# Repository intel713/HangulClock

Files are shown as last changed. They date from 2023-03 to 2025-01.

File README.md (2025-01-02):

# HangulClock
현재 시각에 맞는 한글에 불을 밝힘으로써 시각을 나타내는 시계<br>

# 사용 부품
1 * `Arduino Nano`<br>
36 * `Adafruit Neopixel`(IP30, 60Led/m)<br>
1 * RTC모듈(`DS1302` OR `DS3231`(추천))<br>

# 참고사항
업로드를 하려면 아두이노 IDE 라이브러리에 `Adafruit_NeoPixel`, `ThreeWire` , `RtcDS1302`(`DS1302`의 경우) / `DS3231`(`DS3231`의 경우)라이브러리가 포함되어 있어야 함.<br>
`DS3231` 라이브러리 [GitHub 링크](https://github.com/NorthernWidget/DS3231)<br>
ShortCable:네오픽셀 간 케이블 연결 길이를 최소화 하기 위해 네오픽셀을 지그재그로 배치한 버전(파일 내 LED 인덱스 배치 주석 참고).<br>

__알 수 없는 이유로 DS3231 라이브러리가 제대로 안되는 문제가 발생하여 Adafruit의 RTClib로 대체함.__

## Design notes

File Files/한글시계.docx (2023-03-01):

오 전 후 한 두 세

네 다 섯 여 섯 일

곱 여 덟 아 홉 열

한 두 시 이 삼 사

오 십 일 이 삼 사

오 육 칠 팔 구 분

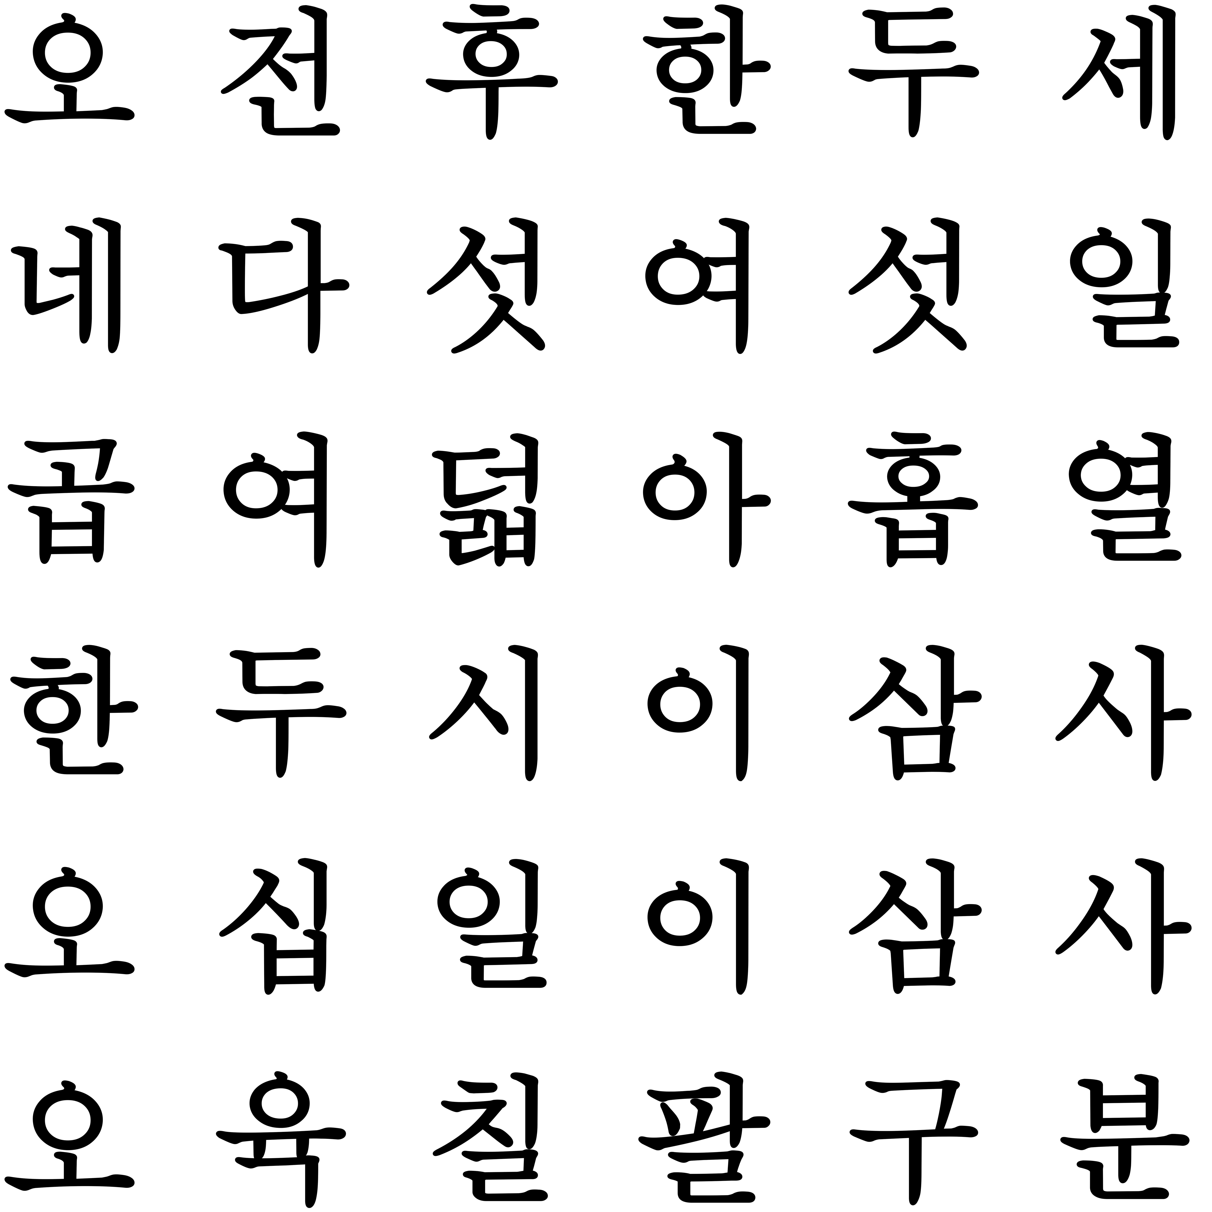
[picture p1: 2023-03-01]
Files/한글시계.png

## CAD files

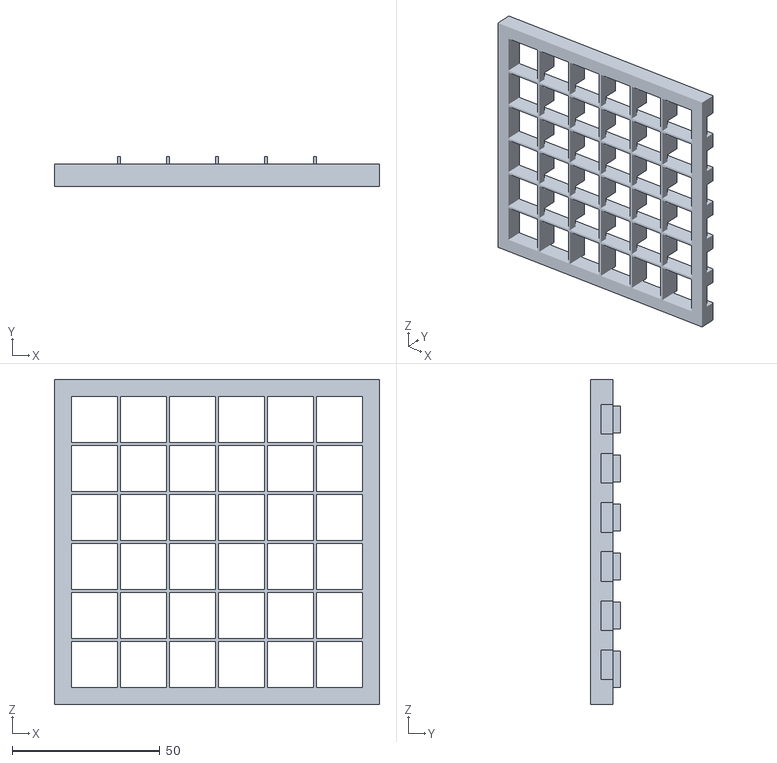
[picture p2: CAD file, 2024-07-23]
STL_V2/sep.stl
110.0 x 10.0 x 110.0

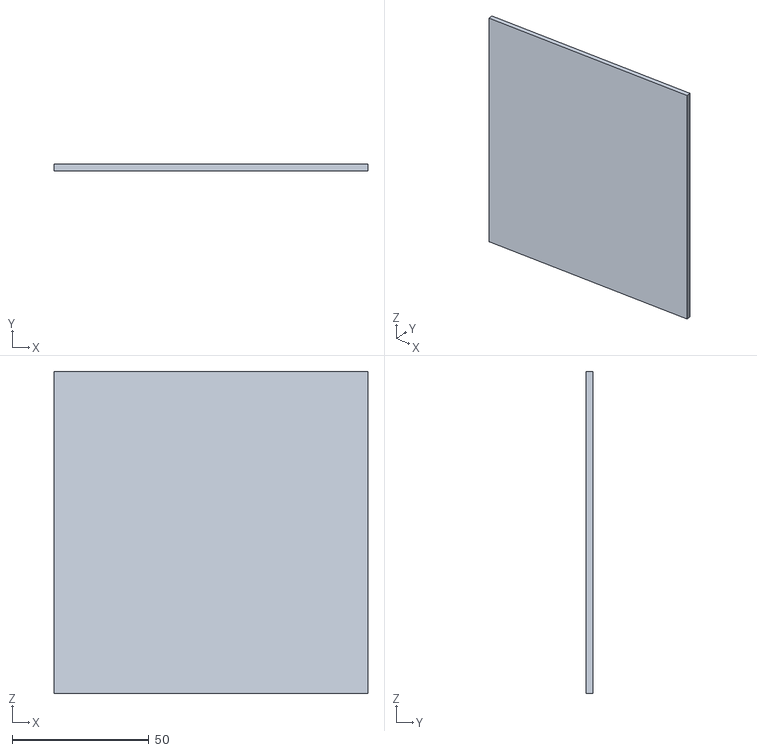
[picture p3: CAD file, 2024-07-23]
STL_V2/back.stl
115.0 x 2.40 x 118.0

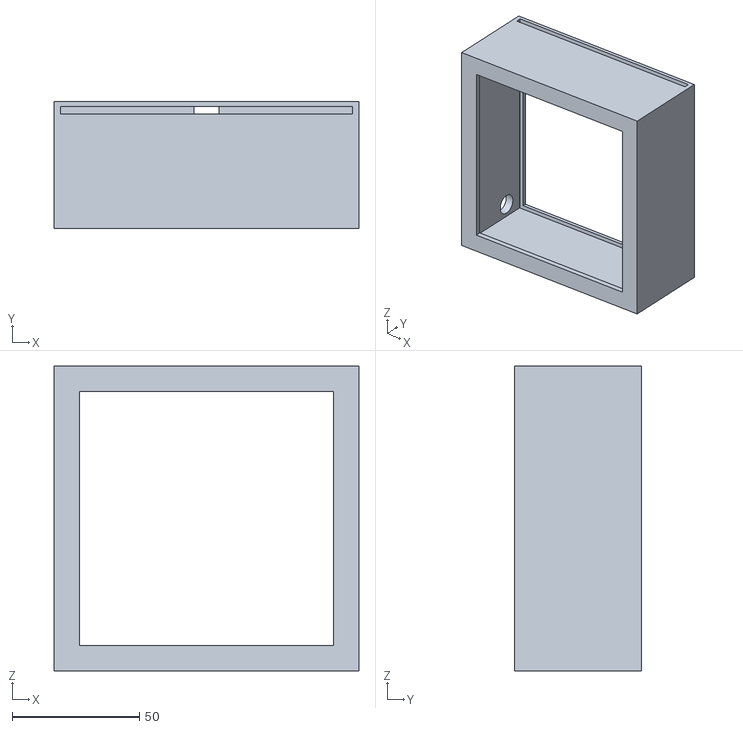
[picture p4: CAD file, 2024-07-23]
STL_V2/case_round.stl
120.0 x 50.0 x 120.0

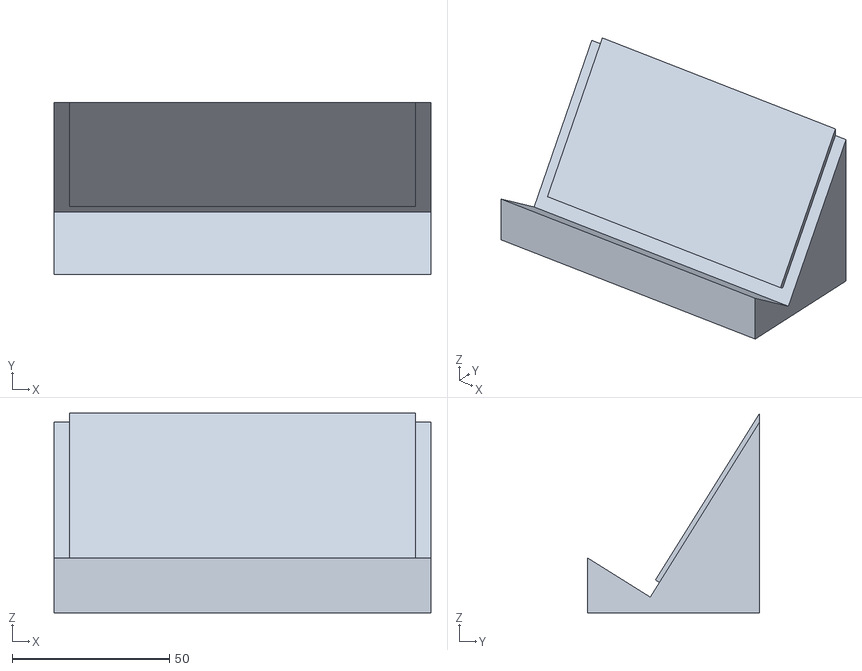
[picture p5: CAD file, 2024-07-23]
STL_V2/support.stl
120.0 x 54.8 x 63.5

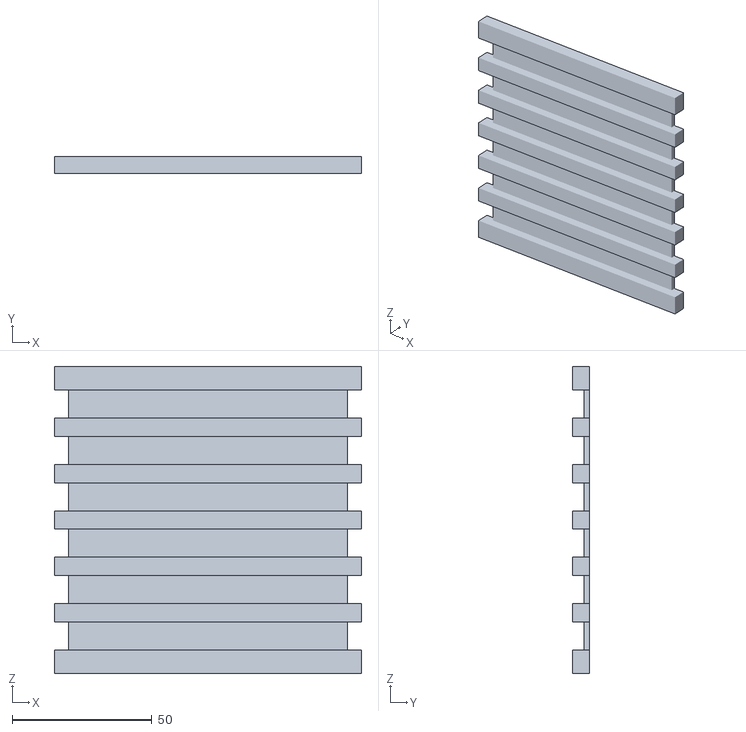
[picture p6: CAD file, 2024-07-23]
STL_V2/led.stl
110.0 x 6.00 x 110.0

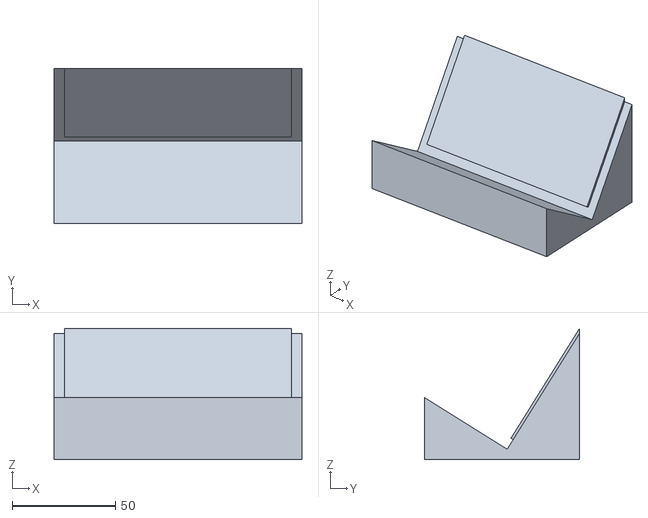
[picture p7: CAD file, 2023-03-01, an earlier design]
STL/Stand.stl
120.0 x 75.0 x 63.4

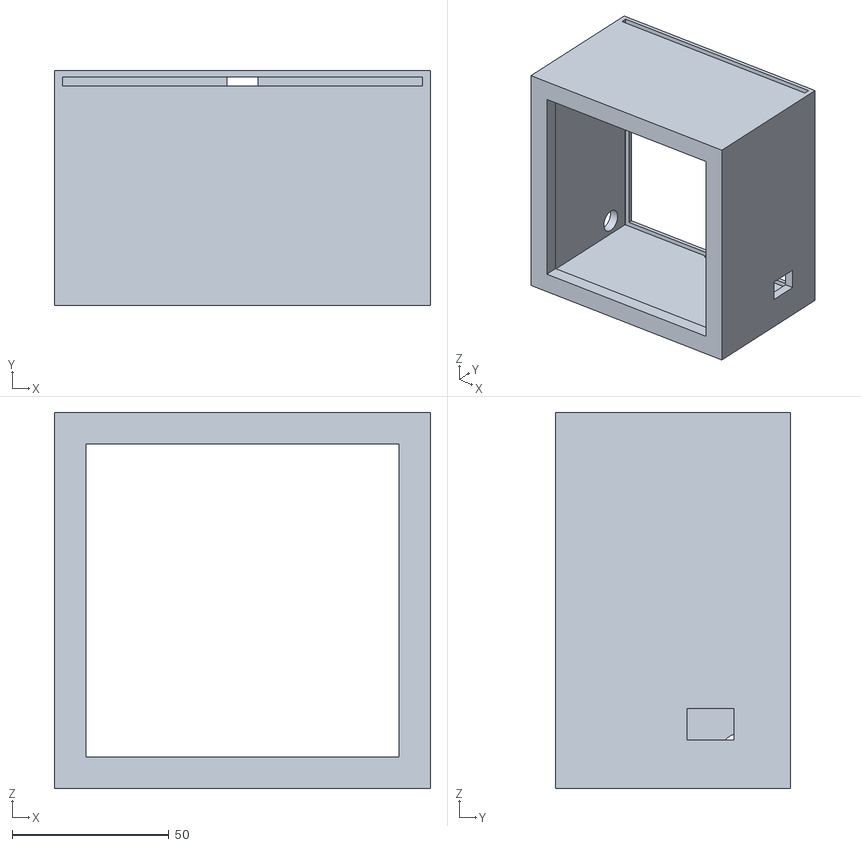
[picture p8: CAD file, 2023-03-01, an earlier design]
STL/Case.stl
120.0 x 75.0 x 120.0

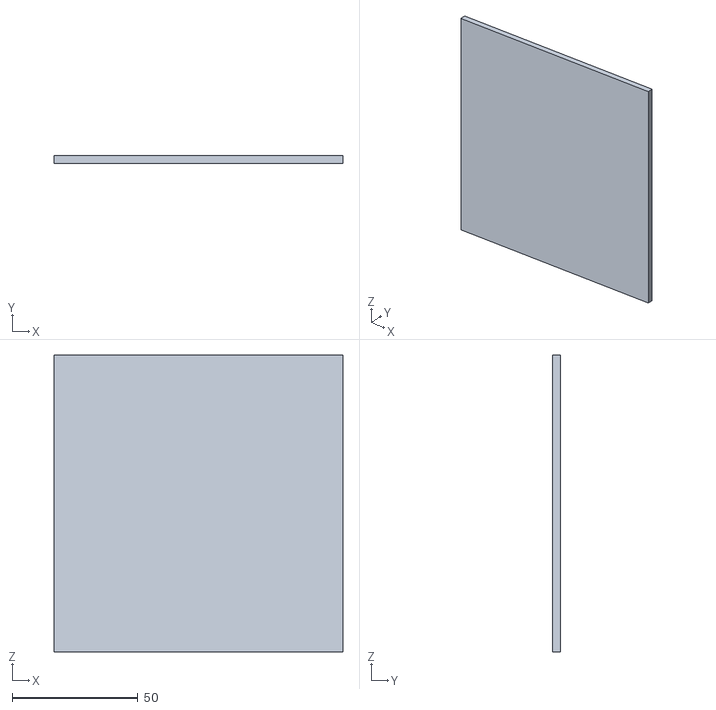
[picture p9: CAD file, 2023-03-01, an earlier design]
STL/Back_Lid.stl
115.0 x 3.00 x 118.0

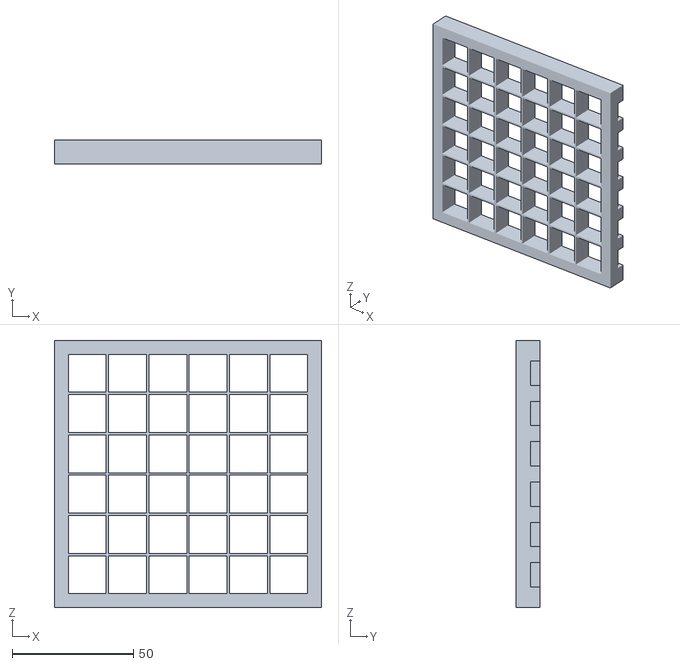
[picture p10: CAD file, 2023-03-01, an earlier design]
STL/Grid.stl
110.0 x 10.0 x 110.0

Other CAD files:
STL_V2/case_usb.stl
STL/Led_Panel.stl

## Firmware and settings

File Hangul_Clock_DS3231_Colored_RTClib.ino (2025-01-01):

//#include <DS3231.h>
#include <Adafruit_NeoPixel.h>
#include <Wire.h>
#include <time.h>
#include "RTClib.h"

#define LED_PIN 3 //네오픽셀 Data 단자와 연결할 핀
#define LED_COUNT 36 //네오픽셀 LED 개수 (6 X 6)

RTC_DS3231 RTC;
Adafruit_NeoPixel strip(LED_COUNT, LED_PIN, NEO_GRB + NEO_KHZ800);

//색과 밝기 설정
#define DEFAULT_COLOR strip.Color(255, 255, 255)
#define BRIGHTNESS 255

#define AM_COLOR strip.Color(255, 255, 32)
#define PM_COLOR strip.Color(96, 64, 255)

#define hour_startH 7000
#define hour_endH 30000

#define minute_startH 500
#define minute_endH 6000

uint32_t hour_color = strip.Color(255, 255, 255);
uint32_t minute_color = strip.Color(225, 115, 44);

/* 위치 구성
오 전 후 한 두 세
네 다 섯 여 섯 일
곱 여 덟 아 홉 열
한 두 시 이 삼 사
오 십 일 이 삼 사
오 육 칠 팔 구 분
00 01 02 03 04 05
06 07 08 09 10 11
12 13 14 15 16 17
18 19 20 21 22 23
24 25 26 27 28 29
30 31 32 33 34 35
*/


bool h12 = false, hPM = false;

bool am = true;
int h = 0;
int m = 0;
//int s = 0;

void setup() {
  strip.begin();
  strip.setBrightness(BRIGHTNESS);
  RTC.begin();
  Serial.begin(115200);
}

void loop() {
  strip.clear();
  setTime();
  setColor();
  setAmPm();
  setHour();
  setMinute();
  strip.show();
  delay(100);

  /*
  for (int i = 0; i <= 23; i++) {
    for (int j = 0; j <= 59; j++) {
      h = i;
      m = j;

      strip.clear();
      setAmPm();
      setColor();
      setHour();
      setMinute();
      strip.show();
      delay(5);
    }
  }
  */
}


void setTime()
{
  DateTime now = RTC.now();
  
  h = now.hour();
  m = now.minute();
  //s = RTC.getSecond();
}

void setAmPm()
{
  if (0 <= h and h < 12){
    strip.setPixelColor(0, AM_COLOR);
    strip.setPixelColor(1, AM_COLOR);
    if (h == 0) {
      h = 12;
      am = true;
    }
  }
  else {
    strip.setPixelColor(0, PM_COLOR);
    strip.setPixelColor(2, PM_COLOR);
    am = false;
    if (h != 12) {
      h = h - 12;
    }
  }
}

void setHour()
{
  strip.setPixelColor(20, hour_color); //시

  if (h == 1) {
    strip.setPixelColor(3, hour_color);
  }
  else if (h == 2) {
    strip.setPixelColor(4, hour_color);
  }
  else if (h == 3) {
    strip.setPixelColor(5, hour_color);
  }
  else if (h == 4) {
    strip.setPixelColor(6, hour_color);
  }
  else if (h == 5) {
    strip.setPixelColor(7, hour_color);
    strip.setPixelColor(8, hour_color);
  }
  else if (h == 6) {
    strip.setPixelColor(9, hour_color);
    strip.setPixelColor(10, hour_color);
  }
  else if (h == 7) {
    strip.setPixelColor(11, hour_color);
    strip.setPixelColor(12, hour_color);
  }
  else if (h == 8) {
    strip.setPixelColor(13, hour_color);
    strip.setPixelColor(14, hour_color);
  }
  else if (h == 9) {
    strip.setPixelColor(15, hour_color);
    strip.setPixelColor(16, hour_color);
  }
  else if (h == 10) {
    strip.setPixelColor(17, hour_color);
  }
  else if (h == 11) {
    strip.setPixelColor(17, hour_color);
    strip.setPixelColor(18, hour_color);
  }
  else if (h == 12) {
    strip.setPixelColor(17, hour_color);
    strip.setPixelColor(19, hour_color);
  }
}

void setMinute()
{
  if (m >= 10) {
    strip.setPixelColor(25 , minute_color);
    if (m >= 20) {
      strip.setPixelColor((m / 10) + 19, minute_color);
    }
  }
  if (m != 0) {
    strip.setPixelColor((m % 10) + 25, minute_color);
    
    strip.setPixelColor(35, minute_color); //분
  }
}

void setColor()
{
  // if (am == true)
  // {
  //   if (0 <= h and h < 6 or h == 12)
  //   {
  //     hour_color = strip.Color(9, 24, 63);
  //     //minute_color = strip.Color(9, 24, 63);
  //   }
  //   else if (6 <= h and h < 7)
  //   {
  //     hour_color = strip.Color(170, 113, 132);
  //     //minute_color = strip.Color(170, 113, 132);
  //   }
  //   else if (7 <= h and h < 9)
  //   {
  //     hour_color = strip.Color(235, 216, 131);
  //     //minute_color = strip.Color(235, 216, 131);
  //   }
  //   else if (9 <= h and h < 12)
  //   {
  //     hour_color = strip.Color(146, 204, 252);
  //     //minute_color = strip.Color(146, 204, 252);
  //   }
  // }
  // else
  // {
  //   if (0 <= h and h < 4 or h == 12)
  //   {
  //     hour_color = strip.Color(60, 131, 210);
  //     //minute_color = strip.Color(60, 131, 210);
  //   }
  //   else if (4 <= h and h < 6)
  //   {
  //     hour_color = strip.Color(225, 115, 44);
  //     //minute_color = strip.Color(225, 115, 44);
  //   }
  //   else if (6 <= h and h < 8)
  //   {
  //     hour_color = strip.Color(99, 80, 135);
  //     //minute_color = strip.Color(99, 80, 135);
  //   }
  //   else if (8 <= h and h < 12)
  //   {
  //     hour_color = strip.Color(9, 24, 63);
  //     //minute_color = strip.Color(9, 24, 63);
  //   }
  // }


  hour_color = strip.ColorHSV(map(h, 0, 23, hour_startH, hour_endH), 255, 255);
  minute_color = strip.ColorHSV(map(m, 0, 59, minute_startH, minute_endH), 255, 255);
}

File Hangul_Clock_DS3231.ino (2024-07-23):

#include <DS3231.h>
#include <Adafruit_NeoPixel.h>
#include <Wire.h>
#include <time.h>

#define LED_PIN 5 //네오픽셀 Data 단자와 연결할 핀
#define LED_COUNT 36 //네오픽셀 LED 개수 (6 X 6)

DS3231 RTC;
Adafruit_NeoPixel strip(LED_COUNT, LED_PIN, NEO_GRB + NEO_KHZ800);

/* 위치 구성
오 전 후 한 두 세
네 다 섯 여 섯 일
곱 여 덟 아 홉 열
한 두 시 이 삼 사
오 십 일 이 삼 사
오 육 칠 팔 구 분
00 01 02 03 04 05
06 07 08 09 10 11
12 13 14 15 16 17
18 19 20 21 22 23
24 25 26 27 28 29
30 31 32 33 34 35
*/

//색과 밝기 설정
int r = 255;
int g = 255;
int b = 255;
int brightness = 255;

bool h12 = false, hPM = false;

void setup() {
  strip.begin();
  strip.setBrightness(brightness);
  //Serial.begin(57600);
}

int h = 0;
int m = 0;
//int s = 0;

void loop() {
  strip.clear();
  strip.setPixelColor(0, r, g, b); //오(전/후)
  strip.setPixelColor(20, r, g, b); //시
  setTime();
  setAmPm();
  setHour();
  setMinute();
  strip.show();
  delay(200);
}


void setTime() {
  h = RTC.getHour(h12, hPM);
  m = RTC.getMinute();
  //s = RTC.getSecond();
}

void setAmPm() {
  if (h >= 0 && h < 12){
    strip.setPixelColor(1, r, g, b);
    if (h == 0) {
      h = 12;
    }
  }
  else {
    strip.setPixelColor(2, r, g, b);
    if (h != 12) {
      h = h - 12;
    }
  }
}

void setHour() {
  if (h == 1) {
    strip.setPixelColor(3, r, g, b);
  }
  else if (h == 2) {
    strip.setPixelColor(4, r, g, b);
  }
  else if (h == 3) {
    strip.setPixelColor(5, r, g, b);
  }
  else if (h == 4) {
    strip.setPixelColor(6, r, g, b);
  }
  else if (h == 5) {
    strip.setPixelColor(7, r, g, b);
    strip.setPixelColor(8, r, g, b);
  }
  else if (h == 6) {
    strip.setPixelColor(9, r, g, b);
    strip.setPixelColor(10, r, g, b);
  }
  else if (h == 7) {
    strip.setPixelColor(11, r, g, b);
    strip.setPixelColor(12, r, g, b);
  }
  else if (h == 8) {
    strip.setPixelColor(13, r, g, b);
    strip.setPixelColor(14, r, g, b);
  }
  else if (h == 9) {
    strip.setPixelColor(15, r, g, b);
    strip.setPixelColor(16, r, g, b);
  }
  else if (h == 10) {
    strip.setPixelColor(17, r, g, b);
  }
  else if (h == 11) {
    strip.setPixelColor(17, r, g, b);
    strip.setPixelColor(18, r, g, b);
  }
  else if (h == 12) {
    strip.setPixelColor(17, r, g, b);
    strip.setPixelColor(19, r, g, b);
  }
}

void setMinute() {
  if (m >= 10) {
    strip.setPixelColor(25 , r, g, b);
    if (m >= 20) {
      strip.setPixelColor((m / 10) + 19, r, g, b);
    }
  }
  if (m != 0) {
    strip.setPixelColor((m % 10) + 25, r, g, b);
    
    strip.setPixelColor(35, r, g, b); //분
  }
}#include <DS3231.h>
#include <Adafruit_NeoPixel.h>
#include <Wire.h>
#include <time.h>

#define LED_PIN 5 //네오픽셀 Data 단자와 연결할 핀
#define LED_COUNT 36 //네오픽셀 LED 개수 (6 X 6)

DS3231 RTC;
Adafruit_NeoPixel strip(LED_COUNT, LED_PIN, NEO_GRB + NEO_KHZ800);

/* 위치 구성
오 전 후 한 두 세
네 다 섯 여 섯 일
곱 여 덟 아 홉 열
한 두 시 이 삼 사
오 십 일 이 삼 사
오 육 칠 팔 구 분
00 01 02 03 04 05
06 07 08 09 10 11
12 13 14 15 16 17
18 19 20 21 22 23
24 25 26 27 28 29
30 31 32 33 34 35
*/

//색과 밝기 설정
int r = 255;
int g = 255;
int b = 255;
int brightness = 255;

bool h12 = false, hPM = false;

void setup() {
  strip.begin();
  strip.setBrightness(brightness);
  //Serial.begin(57600);
}

int h = 0;
int m = 0;
//int s = 0;

void loop() {
  strip.clear();
  strip.setPixelColor(0, r, g, b); //오(전/후)
  strip.setPixelColor(20, r, g, b); //시
  setTime();
  setAmPm();
  setHour();
  setMinute();
  strip.show();
  delay(200);
}


void setTime() {
  h = RTC.getHour(h12, hPM);
  m = RTC.getMinute();
  //s = RTC.getSecond();
}

void setAmPm() {
  if (h >= 0 && h < 12){
    strip.setPixelColor(1, r, g, b);
    if (h == 0) {
      h = 12;
    }
  }
  else {
    strip.setPixelColor(2, r, g, b);
    if (h != 12) {
      h = h - 12;
    }
  }
}

void setHour() {
  if (h == 1) {
    strip.setPixelColor(3, r, g, b);
  }
  else if (h == 2) {
    strip.setPixelColor(4, r, g, b);
  }
  else if (h == 3) {
    strip.setPixelColor(5, r, g, b);
  }
  else if (h == 4) {
    strip.setPixelColor(6, r, g, b);
  }
  else if (h == 5) {
    strip.setPixelColor(7, r, g, b);
    strip.setPixelColor(8, r, g, b);
  }
  else if (h == 6) {
    strip.setPixelColor(9, r, g, b);
    strip.setPixelColor(10, r, g, b);
  }
  else if (h == 7) {
    strip.setPixelColor(11, r, g, b);
    strip.setPixelColor(12, r, g, b);
  }
  else if (h == 8) {
    strip.setPixelColor(13, r, g, b);
    strip.setPixelColor(14, r, g, b);
  }
  else if (h == 9) {
    strip.setPixelColor(15, r, g, b);
    strip.setPixelColor(16, r, g, b);
  }
  else if (h == 10) {
    strip.setPixelColor(17, r, g, b);
  }
  else if (h == 11) {
    strip.setPixelColor(17, r, g, b);
    strip.setPixelColor(18, r, g, b);
  }
  else if (h == 12) {
    strip.setPixelColor(17, r, g, b);
    strip.setPixelColor(19, r, g, b);
  }
}

void setMinute() {
  if (m >= 10) {
    strip.setPixelColor(25 , r, g, b);
    if (m >= 20) {
      strip.setPixelColor((m / 10) + 19, r, g, b);
    }
  }
  if (m != 0) {
    strip.setPixelColor((m % 10) + 25, r, g, b);
    
    strip.setPixelColor(35, r, g, b); //분
  }
}
